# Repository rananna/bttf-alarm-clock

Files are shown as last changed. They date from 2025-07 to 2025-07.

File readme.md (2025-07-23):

# Back to the Future - ESP32 Alarm Clock

<p align="center">
  
  
</p>

<p align="center">
  <!-- Replace with a GIF or image of your clock in action! -->
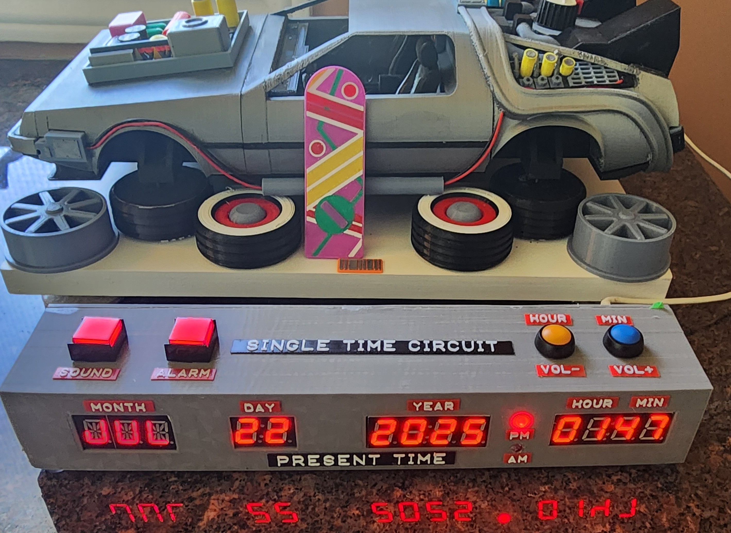
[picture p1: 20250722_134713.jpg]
  
</p>

> **Great Scott!** It appears you've stumbled upon the schematics for a temporal displacement alarm clock. While this device can't actually travel through time (flux capacitor technology is still a bit tricky), it brings the iconic look and feel of the DeLorean's time circuits right to your nightstand. Using the power of an ESP32 and a little bit of 1.21-gigawatt... I mean, 5-volt... ingenuity, this clock connects to your local WiFi network to display the precise date and time. You can set a "Destination Time" alarm and a "Last Time Departed" sleep schedule, all configurable from a web interface. So, fire it up, but be warned: once this baby hits 88 miles per hour on the display, you're going to see some serious stuff!

---

### Table of Contents
- [Quick Start](#quick-start)
- [Features](#features)
- [Bill of Materials (BOM)](#bill-of-materials-bom)
- [Software & Libraries](#software--libraries)
- [Wiring Guide](#wiring-guide)
- [Installation & Setup](#installation--setup)
- [Usage](#usage)
  - [Web Interface](#web-interface)
  - [Physical Buttons](#physical-buttons)
- [Troubleshooting](#troubleshooting)
- [Example Usage](#example-usage)
 - [Video Demo](#video-demo)
- [Contributing](#contributing)
- [License](#license)
- [Acknowledgements](#acknowledgements)

## Quick Start

For experienced makers:
1.  **Gather Components**: Check the [Bill of Materials](#bill-of-materials-bom).
2.  **Assemble Hardware**: Solder components and follow the [Wiring Guide](#wiring-guide).
3.  **Prepare SD Card**: Format a MicroSD card (FAT32), create an `/mp3` folder, and copy sound files named `0001.mp3`, `0002.mp3`, etc., one by one in order.
4.  **Flash Firmware**: Open the project in the Arduino IDE or PlatformIO, install the required libraries, and upload the code to your ESP32.
5.  **Configure WiFi**: After flashing, connect to the `bttf-clock` WiFi network with your phone/PC; a captive portal will appear, allowing you to connect the clock to your home network.
6.  **Configure Clock**: Access the web interface at `http://bttf-alarmclock.local` to set the time zone, alarm, and other features.

    *Note:* If the clock is in Access Point mode (i.e., it couldn't connect to a saved WiFi network), the alphanumeric display will show "AP" to indicate this mode.
## Features

<p align="center">
  <!-- Replace with a GIF or image of your clock in action! -->
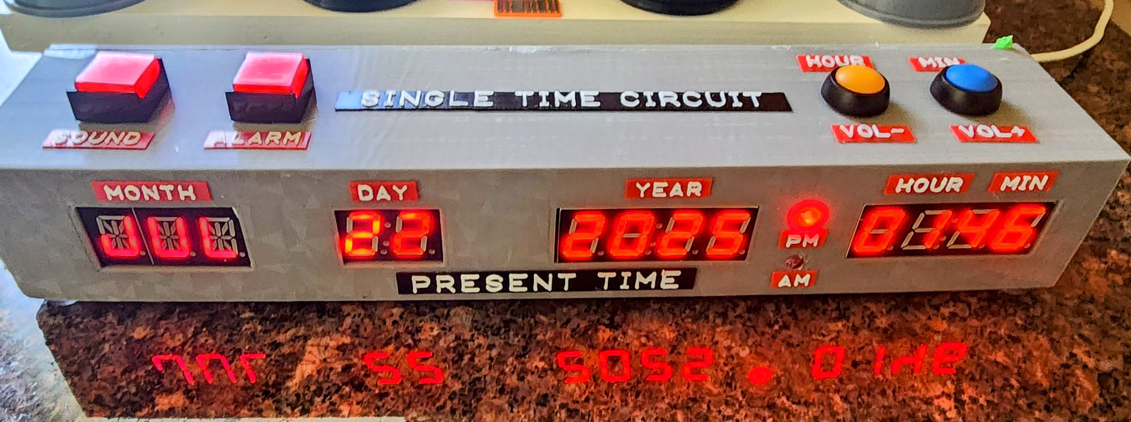
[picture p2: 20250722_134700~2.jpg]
  
</p>

### Video Demo

You can see the BTTF clock booting up [here](https://youtu.be/V0ri4ddPnqE?si=vd6oWths4MbNTJP2)

This project is packed with features to create an authentic and highly functional alarm clock:

*   **BTTF-Themed Display Layout**: Four displays work together to show the current date and time.
    *   **Month**: An alphanumeric display shows the three-letter month abbreviation (e.g., `JUL`).
    *   **Day**: A 7-segment display shows the day of the month.
    *   **Year**: A 7-segment display shows the full year.
    *   **Time**: A 7-segment display shows the current hour and minute, with a blinking colon.
*   **Accurate & Automatic Time**:
    *   **NTP Time Synchronization**: Automatically fetches and syncs time from multiple fallback NTP servers for high reliability.
    *   **Full Time Zone Support**: Includes automatic Daylight Saving Time adjustments, configurable via the web UI.
*   **Complete Web Interface**:
    *   **Web Configuration Portal**: Configure all settings easily from any device on your network via a web browser at `http://bttf-alarmclock.local`.
    *   **WiFi Manager**: Simple initial WiFi setup using a captive portal. No need to hardcode credentials.
*   **Advanced Alarm System**:
    *   **Configurable Alarm**: Set alarm time, toggle on/off, and configure snooze duration from the web UI or physical buttons.
    *   **Snooze Functionality**: Snooze the alarm with a press of a button.
*   **Authentic Experience**:
    *   **Sound Effects**: Plays iconic sounds from the movie for alarms and animations using a DFPlayer Mini MP3 module.
    *   **Time Travel Animations**: Watch the displays go haywire and the speedometer hit 88 MPH at configurable intervals!
*   **Customization & Convenience**:
    *   **Power Saving Mode**: Displays automatically turn off during user-defined "sleep" hours to save power and avoid nighttime glare.
    *   **Over-The-Air (OTA) Updates**: Update the firmware wirelessly over your WiFi network.
    *   **Web UI Themes**: Change the color scheme of the web interface to match your favorite BTTF aesthetic.
    *   **Physical Button Controls**: Full control over core functions without needing the web UI.

## Bill of Materials (BOM)

This project requires a handful of common electronics components. Below is a consolidated Bill of Materials (BOM) for everything you'll need to assemble the clock. The links provided are examples; feel free to source components from your preferred supplier.

| Category | Component | Qty | Notes |
| :--- | :--- | :---: | :--- |
| **Microcontroller** | [ESP32 Dev Module](https://www.aliexpress.com/item/1005006212080137.html) | 1 | The brain of the project. Any ESP32 with enough GPIO pins will work. |
| **Audio** | [DFPlayer Mini MP3 Module](https://www.aliexpress.com/item/1005008228039985.html) | 1 | For playing sound effects. |
| | [MicroSD Card](https://www.aliexpress.com/item/1005008978876553.html) | 1 | 1GB or larger, formatted to FAT16 or FAT32. For storing MP3 files. |
| | [Small Speaker](https://www.aliexpress.com/item/1005006682079525.html) | 1 | A small 8 Ohm speaker (e.g., 0.5W or 1W) for sound output. |
| **Displays** | [TM1637 7-Segment Display](https://www.aliexpress.com/item/1005001582129952.html) | 3 | 4-digit displays for Day, Year, and Time. |
| | [Adafruit AlphaNum4 Display](https://www.aliexpress.com/item/1005001593666162.html) | 1 | 14-segment I2C display for the month. Any HT16K33-based display should work. |
| **User Input** | [Lighted Tactile Push Buttons](https://www.aliexpress.com/item/1005007163972572.html) | 2 | For Set/Stop and Sound/Toggle. |
| | [Tactile Push Buttons](https://www.aliexpress.com/item/1005002622143638.html) | 2 | For Hour and Minute. |
| **Indicators** | [5mm LEDs](https://www.aliexpress.com/item/1005003912454852.html) | 2 | For the AM/PM indicators. Any color. |
| **Passive Components** | [10kΩ Resistors](https://www.aliexpress.com/item/1005008722480918.html) | 4 | Pull-down resistors for the buttons. |
| | [220-330Ω Resistors](https://www.aliexpress.com/item/1005002091320103.html) | 4 | Current-limiting resistors for all LEDs (AM, PM, and button LEDs). |
| | [Wago-style Lever Nuts](https://www.aliexpress.com/item/1005009152825193.html) | (Optional) | For cleaner power distribution. |
| **Prototyping** | Solderless Breadboard (optional) | 1 | For initial assembly and testing. |
| | [Dupont Jumper Wires](https://www.aliexpress.com/item/1005003641187997.html) | 1 set | Male-to-Male and Male-to-Female. |
| | 5V Power Supply | 1 | Minimum 1A recommended, especially for the DFPlayer Mini. |
| | [Wago-style Lever Nuts](https://www.aliexpress.com/item/1005009152825193.html) | (Optional) | For cleaner power distribution. |

## Software & Libraries

This project is built using the Arduino framework for the ESP32. You will need to install the following libraries through the Arduino IDE Library Manager or PlatformIO:

| Library | Author | Purpose | Link |
| --- | --- | --- | --- |
| `WiFiManager` | tzapu | For the WiFi connection portal. | [GitHub](https://github.com/tzapu/WiFiManager) |
| `Adafruit GFX Library` | Adafruit | Core graphics library. | [GitHub](https://github.com/adafruit/Adafruit-GFX-Library) |
| `Adafruit LED Backpack Library` | Adafruit | Drives the AlphaNum4 display. | [GitHub](https://github.com/adafruit/Adafruit_LED_Backpack) |
| `DFRobotDFPlayerMini` | DFRobot | Controls the MP3 player module. | [GitHub](https://github.com/DFRobot/DFRobotDFPlayerMini) |
| `ESPAsyncWebServer` | me-no-dev | Hosts the web configuration interface.| [GitHub](https://github.com/me-no-dev/ESPAsyncWebServer) |
| `AsyncTCP` | me-no-dev | Required by ESPAsyncWebServer. | [GitHub](https://github.com/me-no-dev/AsyncTCP) |
| `arduinoJson` | bblanchon | Handles data for the web API. | [GitHub](https://github.com/bblanchon/ArduinoJson) |
| `TM1637` | Avishay Orpaz | Drives the 7-segment displays. | [GitHub](https://github.com/avishorp/TM1637) |

## Wiring Guide

This section provides a detailed overview of how to connect all components to the ESP32. It's highly recommended to assemble the circuit on a breadboard first to test the connections before soldering.

<p align="center">
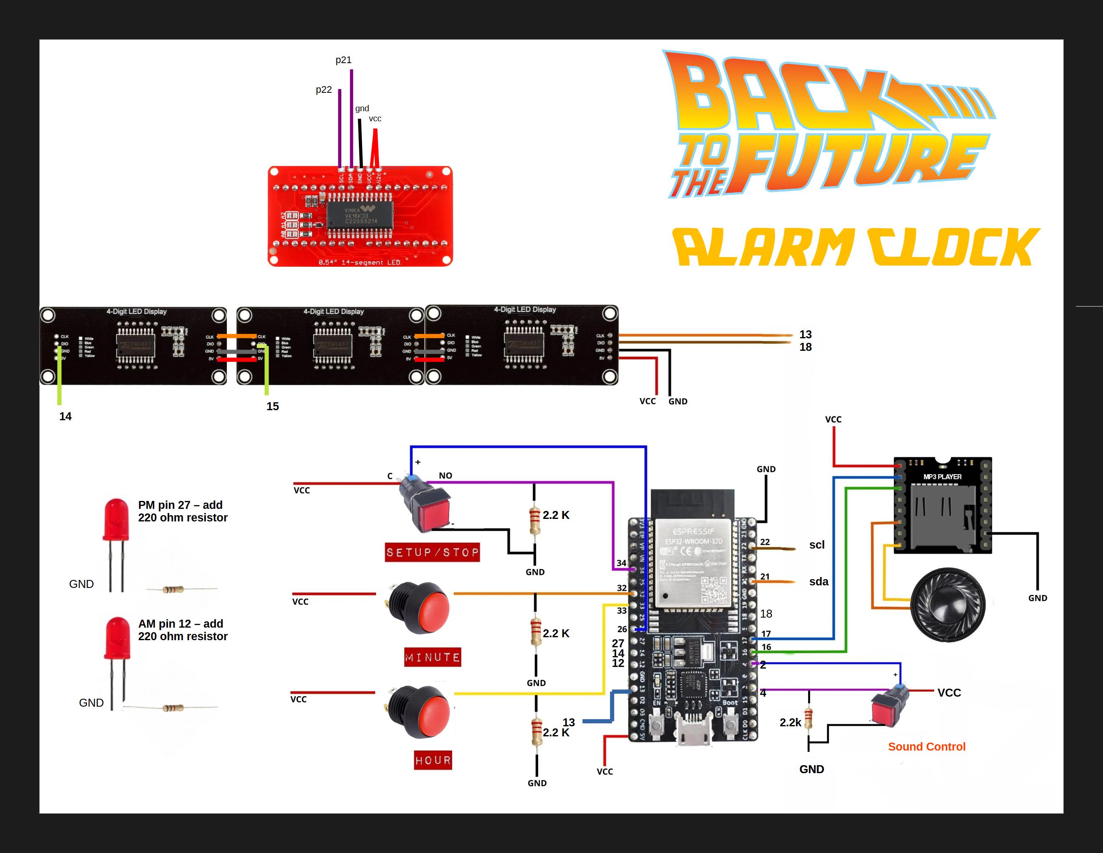
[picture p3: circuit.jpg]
  
</p>

### Power Distribution
**Pro-Tip for Power Rails:** Managing multiple power and ground connections on a breadboard can get messy. For a much cleaner and more reliable setup, consider using **Wago-style lever-nut connectors**. You can run a single wire from your 5V source to one connector and another from GND to a second. Then, simply plug all the individual component VCC and GND wires into their respective connectors. This creates solid, secure power rails without soldering.

All components require a connection to power (VCC) and ground (GND).
*   **5V Power**: Connect the **VIN** pin of the ESP32 to the positive (5V) rail of your power source. Connect the VCC pins of all three TM1637 displays, the Adafruit AlphaNum4 display, and the DFPlayer Mini to this 5V rail.
*   **Ground**: Connect a **GND** pin from the ESP32 to the common ground rail. Connect the GND pins of all displays, the DFPlayer Mini, all buttons, and the negative (cathode) side of all LEDs (via their current-limiting resistors) to this ground rail.
### Display Connections

The clock uses four separate displays that are controlled differently.

### TM1637 7-Segment Displays
These three displays share a common clock (CLK) line to save pins, but each has a unique data (DIO) line.

| Display Function | Pin | ESP32 GPIO |
| --- |:---:| :---: |
| **All TM1637s (Shared)** | CLK | 13 |
| Day of Month | DIO | 18 |
| Year | DIO | 15 |
| Time (HH:MM) | DIO | 14 |

### Adafruit AlphaNum4 Alphanumeric Display
This display uses the I2C communication protocol.

| Component | Pin | ESP32 GPIO |
| --- |:---:| :---: |
| **Adafruit AlphaNum4 (I2C)** | SDA | 21 |
| | SCL | 22 |
### Audio Connections

The DFPlayer Mini module communicates with the ESP32 using a serial (UART) connection.

| Component | Pin | ESP32 GPIO | Notes |
| --- |:---:| :---: | --- |
| **DFPlayer Mini**| RX  |  17 (TXD2) | Connects to the ESP32's **TX** pin. |
| | TX  |  16 (RXD2) | Connects to the ESP32's **RX** pin. |
| | SPK_1 | Speaker +  | Connect one speaker wire here. |
| | SPK_2 | Speaker -  | Connect the other speaker wire here. |

### Button & LED Connections

The buttons require pull-down resistors (e.g., 10kΩ) to prevent floating inputs. The LEDs require current-limiting resistors (e.g., 220-330Ω) to prevent them from burning out.

| Component | ESP32 GPIO | Notes |
| --- | :---: | --- |
| Set/Stop Button | 34 | Connect one side to 3.3V and the other to the GPIO pin. Add a 10kΩ pull-down resistor from the GPIO pin to GND. |
| Set/Sound Button | 4 | Connect one side to 3.3V and the other to the GPIO pin. Add a 10kΩ pull-down resistor from the GPIO pin to GND. |
| Hour Button | 33 | Connect one side to 3.3V and the other to the GPIO pin. Add a 10kΩ pull-down resistor from the GPIO pin to GND. |
| Minute Button | 32 | Connect one side to 3.3V and the other to the GPIO pin. Add a 10kΩ pull-down resistor from the GPIO pin to GND. |
| **AM LED** | 27 | Connect the anode (+) to this pin. Connect cathode (-) to GND via a 220-330Ω resistor. |
| **PM LED** | 12 | Connect the anode (+) to this pin. Connect cathode (-) to GND via a 220-330Ω resistor. |
| Set/Stop LED | 26 | Connect the anode (+) to this pin. Connect cathode (-) to GND via a 220-330Ω resistor. |
| Set/Sound LED | 2 | Connect the anode (+) to this pin. Connect cathode (-) to GND via a 220-330Ω resistor. |
## Installation & Setup

### 1. 3D Print the Housing

A custom-designed housing is available to give your clock an authentic, finished look. The 3D model is provided as a Bambu Studio project file (`bambu studio clock.3mf`).
#
This project's housing is based on the incredible "Back to the Future Single Time Circuit" model by TerryB on MakerWorld. A huge thank you to to him for his original work and the mods he made at my request to the files! You can find the original model [here](https://makerworld.com/en/models/1154106-back-to-the-future-single-time-circuit#profileId-1537667).

*   **File**: `bambu studio clock.3mf`
*   **Recommended Filament**: For a realistic metallic look, use a metallic grey or silver PLA/PETG filament.
*   **Build Plate**: Printing on a patterned or textured PEI build plate can enhance the metallic effect and give the surface a unique finish.
*   **Infill**: Use an infill of **50% or higher** to ensure the housing is sturdy and durable.
*   **Labels**: The labels for the displays and buttons can be printed using the included `bttf-labels.3mf` Bambu Studio project file. To achieve the white text on the black background, you will need to set a filament color change to **white** at the correct layer height within Bambu Studio.

### 2. Hardware Assembly

Solder all the components together as described in the **Wiring Guide**. Double-check all your connections, especially power and ground, before applying power.

**Pro-Tip:** For initial assembly and prototyping, **Dupont plug-in jumper wires** are highly recommended. They eliminate the need for soldering and make wiring much simpler and reversible. For a more permanent and robust final build, consider soldering components to a perfboard.

### 3. Prepare the SD Card

1.  Format a MicroSD card to **FAT16** or **FAT32**.
2.  Create a folder named `mp3` in the root of the SD card.
3.  Copy your sound effect files into the `mp3` folder. The files must be named in a specific four-digit format: `0001.mp3`, `0002.mp3`, etc.
    *   **Important**: Due to how the DFPlayer Mini module indexes files, you must copy the files to the SD card **one by one, in numerical order**. Start with `0001.mp3`, then `0002.mp3`, and so on. Do not copy them all at once, as this can cause the wrong sounds to play.
    *   `0002.mp3`: Time travel / primary alarm sound.
    *   `0008.mp3`: "Power of Love" easter egg sound
    *   `0010.mp3`: Sleep mode activation sound
    *   `0013.mp3`: "On" or positive confirmation sound
    *   `0014.mp3`: "Off" or negative confirmation sound
    *   ... and other random sounds for the alarm (`0001.mp3` - `0009.mp3`)
4.  Insert the SD card into the DFPlayer Mini module.

### 4. Flash the Firmware
1.  **Set Up Your IDE**: This project can be compiled using the **Arduino IDE** or **PlatformIO** (in an editor like VS Code).
    *   **Arduino IDE**: Install the ESP32 board definitions.
    *   **PlatformIO**: The `platformio.ini` file should handle the setup automatically.
2.  **Install Libraries**: Using your IDE's Library Manager, install all the libraries listed in the Software & Libraries section.
3.  **Configure Default Time Zone (Optional)**: The time zone can be set from the web interface later. However, to set the initial default, open the `.ino` file and find the `timezoneString` in the `defaultSettings` struct. Change it to match your local time zone. You can find a list of valid POSIX TZ strings here.
4.  **Upload Code**: Select your ESP32 board model and the correct COM port, then compile and upload the sketch.
### 5. WiFi Configuration

1.  On the first boot (or after resetting WiFi credentials), the clock will create its own WiFi network with the SSID `bttf-clock`.
2.  Connect to this network with your phone or computer.
3.  A captive portal page should automatically open in your browser. If it doesn't, navigate to `192.168.4.1`.
4.  Click "Configure WiFi", select your home WiFi network from the list, and enter your password.
5.  Click "Save". The clock will restart and automatically connect to your network.

## Usage

### Web Interface

Once connected to your WiFi, you can access the full configuration panel by navigating to **http://bttf-alarmclock.local/** in your web browser.

<p align="center">
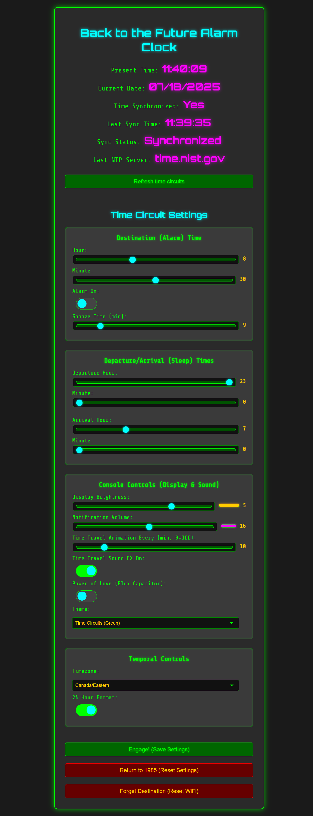
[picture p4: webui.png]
Web UI
  
</p>

From here, you can control all aspects of the clock.
#### Time Circuit Settings
*   **Destination (Alarm) Time**: Use the sliders to set the hour and minute for your alarm.
*   **Alarm On/Off**: A toggle switch to enable or disable the alarm. The `SET/STOP` LED on the clock will light up when the alarm is enabled.
*   **Snooze Time**: A slider to set the snooze duration in minutes (1-59).

#### Departure/Arrival (Sleep) Times
*   These settings define a "sleep" period where the displays will turn off to save power and prevent light disturbance at night.
*   **Departure**: The time the displays will turn off.
*   **Arrival**: The time the displays will turn back on.

#### Display & Sound Settings
*   **Display Brightness**: Adjusts the brightness of all LED displays.
*   **Notification Volume**: Sets the volume for all sound effects from the DFPlayer Mini.
*   **Time Travel Animation Every (min, 0=Off)**: Sets how often (in minutes) the "time travel" animation plays. Set to 0 to disable it.
*   **Time Travel Sound FX On**: A toggle to enable or disable all sound effects, including the alarm. The `SET/SOUND` LED on the clock will light up when sound is enabled.
*   **Power of Love (Flux Capacitor)**: A toggle that triggers the "Power of Love" easter egg sound. This is a one-time trigger and will turn itself off after being activated.
*   **Theme**: A dropdown to change the color scheme of the web interface.

#### Time Settings
*   **Timezone**: Select your local timezone from the dropdown list. This is crucial for correct time display and automatic Daylight Saving Time adjustments.
*   **24 Hour Format**: A toggle to switch the time display between 24-hour format (e.g., 14:30) and 12-hour AM/PM format (e.g., 02:30 PM).

#### Device Management
*   **Save All Settings**: Saves all your changes to the ESP32's memory.
*   **Reset to Default Settings**: Resets all clock settings to their original values and reboots the device.
*   **Reset WiFi Credentials**: Clears the saved WiFi network, reboots the device, and puts it back into AP mode for new WiFi configuration.
### Physical Buttons

The clock can also be operated using the four physical buttons for core functions.

*   **SET/STOP Button**:
    *   **Single Press**: Toggles the main alarm On or Off. A confirmation sound will play, and the corresponding LED will turn on or off.
    *   **Press and Hold**: Enters alarm setting mode.
        *   The time display shows the current alarm time.
        *   While holding, use the **HOUR** and **MINUTE** buttons to adjust the alarm.
        *   Release to save the new alarm time.
    *   **During Alarm**: Stops the currently sounding alarm.

*   **SET/SOUND Button**:
    *   **Single Press**: Toggles all sound effects On or Off. A confirmation sound will play, and the corresponding LED will turn on or off.

*   **HOUR Button**:
    *   **Default Mode**: Decreases the sound effect volume by one step.
    *   **Alarm Setup Mode**: Increments the alarm hour.
    *   **During Alarm**: Activates the **Snooze** function.

*   **MINUTE Button**:
    *   **Default Mode**: Increases the sound effect volume by one step.
    *   **Alarm Setup Mode**: Increments the alarm minute.
    *   **During Alarm**: Activates the **Snooze** function.

*   **Easter Egg**:
    *   Press and hold the **HOUR** and **MINUTE** buttons simultaneously to trigger the "Power of Love" sound effect!

## Troubleshooting
Having trouble? Here are some common issues and their solutions.
*   **Web Interface Not Loading (`bttf-alarmclock.local` doesn't work)**
    *   **mDNS Issues**: Not all networks or operating systems handle `.local` addresses well. Find the clock's IP address from your router's connected devices list or by watching the Serial Monitor in the Arduino IDE when the clock boots up. You can then access the UI by typing the IP address directly into your browser.
    *   **WiFi Connection**: Ensure the ESP32 is connected to your WiFi. If not, it will revert to AP mode (`bttf-clock` network).

*   **Displays Are Not Working or Showing Gibberish**
    *   **TM1637s (Day, Year, Time)**: Double-check the `CLK` and `DIO` wiring. All three displays share the same `CLK` pin, but each must have its own unique `DIO` pin connected to the correct GPIO on the ESP32.
    *   **AlphaNum4 (Month)**: This is an I2C device. Verify that `SDA` and `SCL` are not swapped. You can run an "I2C Scanner" sketch on the ESP32 to confirm the display is detected at address `0x70`.
    *   **Power**: Ensure all displays are receiving a stable 5V.

*   **No Sound from DFPlayer Mini**
    *   **Power Supply**: The DFPlayer can be sensitive to power fluctuations. Ensure you are using a stable 5V power supply capable of providing at least 1A. Powering everything directly from a computer's USB port might be insufficient.
    *   **Wiring**: The most common issue is swapping the RX/TX lines. The DFPlayer's `RX` pin must connect to the ESP32's **TX** pin (`GPIO 17`), and the DFPlayer's `TX` pin must connect to the ESP32's **RX** pin (`GPIO 16`).
    *   **SD Card Format**: The card **must** be formatted as FAT16 or FAT32.
    *   **File Structure**: Ensure there is a folder named `mp3` in the root of the SD card and that your sound files are inside it.
    *   **File Naming & Copying**: Files must be named `0001.mp3`, `0002.mp3`, etc. **Crucially**, you must copy them to the SD card one by one, in numerical order. If you copy them all at once, the player's file index will be incorrect.

*   **Time is Incorrect**
    *   **WiFi**: The clock needs an internet connection to sync with NTP servers.
    *   **Timezone**: Make sure you have selected the correct timezone in the web UI and saved the settings.
    *   **Firewall**: Some restrictive networks may block NTP traffic (UDP port 123).

*   **Buttons Are Unresponsive or Behave Erratically**
    *   **Pull-Down Resistors**: Each button requires a 10kΩ pull-down resistor connecting its GPIO pin to Ground (GND). Without these, the input pin is "floating" and can trigger randomly.
    *   **Wiring**: Double-check that one side of the button is connected to 3.3V and the other side is connected to both the GPIO pin and the pull-down resistor.

## Example Usage

Let's walk through a common scenario: setting up the clock for a typical weekday morning.

**Goal:**
*   Wake up at **7:30 AM**.
*   The displays should turn off at night, from **11:00 PM** to **6:30 AM**.
*   The clock is located in **New York (Eastern Time)**.
*   The display brightness and alarm volume should be at a comfortable, medium level.
*   The "Time Travel" animation should play every **15 minutes**.
*   Both the alarm and general sound effects should be enabled.

Here’s how you would configure this using the web interface at `http://bttf-alarmclock.local/`:

1.  **Set the Alarm Time**
    In the "Destination (Alarm) Time" section, adjust the sliders to your desired wake-up time.
    ```
    Destination Hour: 7
    Destination Minute: 30
    ```

2.  **Enable the Alarm**
    Ensure the main alarm is active by flipping the toggle switch. The `SET/STOP` LED on the clock will light up.
    ```
    Alarm On/Off: On
    ```

3.  **Set the Sleep Period**
    In the "Departure/Arrival (Sleep) Times" section, define when the displays should turn off and on.
    ```
    Departure (Sleep): 23:00
    Arrival (Wake): 6:30
    ```

4.  **Set the Timezone**
    In the "Temporal Controls" section, select the correct timezone from the dropdown menu to ensure accurate time, including DST changes.
    ```
    Timezone: Canada/Eastern
    ```

5.  **Adjust Display Brightness**
    In "Console Controls," set the `Display Brightness` slider to a medium level, like `4`.
    ```
    Display Brightness: 4
    ```

6.  **Adjust Sound Volume**
    Set the `Notification Volume` slider to a moderate level, such as `20`.
    ```
    Notification Volume: 20
    ```

7.  **Configure Animation Frequency**
    Set how often the time travel animation plays. A 15-minute interval is a good starting point.
    ```
    Time Travel Animation Every: 15 min
    ```

8.  **Enable All Sounds**
    Make sure the `Time Travel Sound FX On` toggle is enabled. The `SET/SOUND` LED on the clock will light up.
    ```
    Time Travel Sound FX On: On
    ```

9.  **Save Your Settings**
    Click the **Engage! (Save Settings)** button at the bottom of the page to apply all your changes.

10. **All Set!**
    Your clock is now configured. It will wake you up at 7:30 AM, stay dark overnight, and provide some fun temporal displacement effects throughout the day.

---

## Contributing

Contributions are what make the open-source community such an amazing place to learn, inspire, and create. Any contributions you make are **greatly appreciated**.

If you have a suggestion that would make this better, please fork the repo and create a pull request. You can also simply open an issue with the tag "enhancement". Don't forget to give the project a star! Thanks again!

---

## License

```text
MIT License

Copyright (c) 2025 Randall North

Permission is hereby granted, free of charge, to any person obtaining a copy
of this software and associated documentation files (the "Software"), to deal
in the Software without restriction, including without limitation the rights
to use, copy, modify, merge, publish, distribute, sublicense, and/or sell
copies of the Software, and to permit persons to whom the Software is
furnished to do so, subject to the following conditions:

The above copyright notice and this permission notice shall be included in all
copies or substantial portions of the Software.

THE SOFTWARE IS PROVIDED "AS IS", WITHOUT WARRANTY OF ANY KIND, EXPRESS OR
IMPLIED, INCLUDING BUT NOT LIMITED TO THE WARRANTIES OF MERCHANTABILITY,
FITNESS FOR A PARTICULAR PURPOSE AND NONINFRINGEMENT. IN NO EVENT SHALL THE
AUTHORS OR COPYRIGHT HOLDERS BE LIABLE FOR ANY CLAIM, DAMAGES OR OTHER
LIABILITY, WHETHER IN AN ACTION OF CONTRACT, TORT OR OTHERWISE, ARISING FROM,
OUT OF OR IN CONNECTION WITH THE SOFTWARE OR THE USE OR OTHER DEALINGS IN THE
SOFTWARE.
```

---

## Acknowledgements

This project wouldn't be possible without the hard work of the open-source community and the creators of the fantastic libraries used. Special thanks to the teams behind the ESP32 Arduino core, WiFiManager, and all the Adafruit and DFRobot libraries. A huge thank you to TerryB on MakerWorld for the original 3D model design and for making modifications upon request.

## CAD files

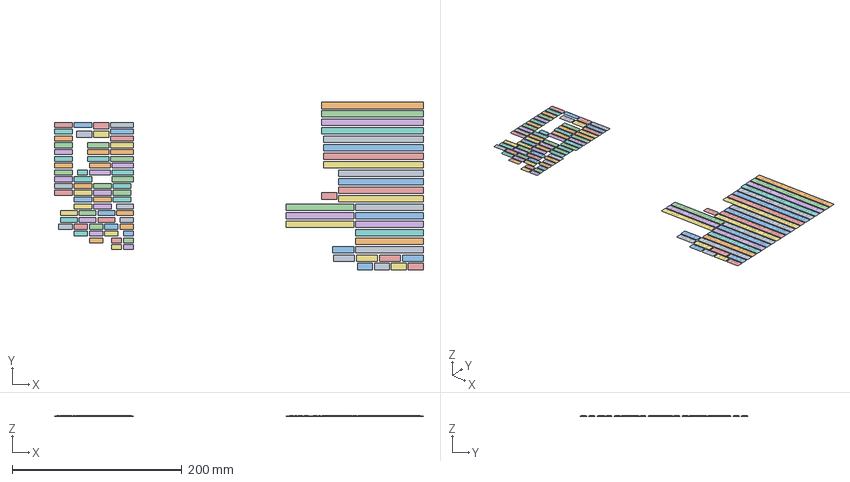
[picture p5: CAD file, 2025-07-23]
bttf-labels.3mf
434.7 x 198.0 x 1.00 mm
month v1.stl x 6
single time circuit.stl x 4
last time departed v1.stl x 4
SOUND.stl x 4
ALARM.stl x 4
destination time v1.stl x 4
TIME CIRCUITS.stl x 5
present time v1.stl x 4
88 v1.stl x 3
year v2.stl x 9
hour v2.stl x 15
set v1.stl x 5
TO v1.stl x 5
VOL-.stl x 4
VOL+.stl x 4
min v2.stl x 7
day v1.stl x 3
am v1.stl x 3
pm v2.stl x 3

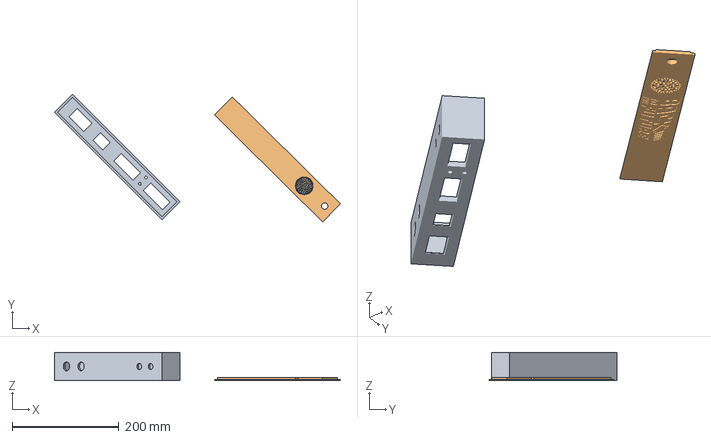
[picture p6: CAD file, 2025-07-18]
clock.3mf
536.0 x 239.6 x 53.0 mm
singlerow.stl
back with speaker.stl

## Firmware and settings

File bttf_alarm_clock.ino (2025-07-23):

/**
 * 
 * Back to the Future Alarm Clock
 * =================================  
 * Author: Randall North              // Your name here
 * Version: 1.0.8 (July 7, 2025)  // Version number and release date
 * Board: ESP32 Dev Module        // Target hardware
 * License: MIT                   // Software license
 * 
 * Description:
 * A WiFi-connected alarm clock inspired by Back to the Future time circuits,
 * with multiple displays showing current, destination and last departure times.
 * 
 * Features:
 * - NTP time synchronization with multiple fallback servers    // Reliable time keeping
 * - Configurable alarm with snooze functionality               // Wake-up capability
 * - OTA updates for easy firmware upgrades                     // Remote updating
 * - Display brightness control with day/night settings         // Eye comfort
 * - Full web configuration interface (http://bttf-alarmclock.local) // Easy configuration
 * - Time travel animations and sound effects                   // Movie authenticity
 * - Multiple display themes (Green, Red, Amber, Blue)          // User customization
 * - Power saving mode during specified hours                   // Energy efficiency
 * - Full time zone support including daylight saving times     // Timekeeping flexibility
 */

#include "Arduino.h"                // Core Arduino functions
#include "TM1637Display.h"          // Library for 7-segment LED displays
#include "WiFiManager.h"            // Handles WiFi connection and captive portal
#include <Wire.h>                   // I2C communication protocol library
#include "Adafruit_GFX.h"           // Graphics library for display control
#include "Adafruit_LEDBackpack.h"   // Controls LED matrix and 7-segment displays
#include "ArduinoOTA.h"             // Over-The-Air firmware updates
#include "ESPmDNS.h"                // Multicast DNS for local hostname resolution
#include "DFRobotDFPlayerMini.h"    // Controls MP3 module for sound effects
#include <WiFi.h>                   // ESP32 WiFi functionality
#include <ESPAsyncWebServer.h>      // Non-blocking web server for configuration interface
#include <Preferences.h>            // ESP32 non-volatile storage for persistent settings
#include <ArduinoJson.h>            // JSON parsing for web API communication
#include <time.h>                   // Time functions for clock operations
#include <WiFiUdp.h>                // UDP protocol for NTP time synchronization
//#include <NTPClient.h>              // NTP client for Internet time synchronization

#define green_CLK 13              // Clock pin for all TM1637 displays
#define green1_DIO 18             // Data pin for the first TM1637 display
#define green2_DIO 15             // Data pin for the second TM1637 display
#define green3_DIO 14             // Data pin for the third TM1637 display
#define greenAM 27                // Output pin to control the AM indicator LED
#define greenPM 12                // Output pin to control the PM indicator LED
#define SET_STOP_BUTTON 34        // Input pin for the Set/Stop button (used to stop alarm or enter settings mode)
#define SET_STOP_LED 26           // Output pin for the LED indicating Set/Stop status
#define SET_SOUND_BUTTON 4        // Input pin for the Set/Sound button (likely for testing sounds or toggling sound-related settings)
#define SET_SOUND_LED 2             // Output pin for the LED indicating Set/Sound status
#define HOUR_BUTTON 33            // Input pin for incrementing the hour in settings mode
#define MINUTE_BUTTON 32          // Input pin for incrementing the minute in settings mode
#define FPSerial Serial1            // Serial port used for communication with the DFPlayer Mini MP3 module

static bool nighttimeonlyonce=true;
struct tm timeinfo;
bool sleeptimeactive = false;
const byte RXD2 = 16;           // RX pin connected to the DFPlayer Mini's TX pin
const byte TXD2 = 17;           // TX pin connected to the DFPlayer Mini's RX pin


DFRobotDFPlayerMini myDFPlayer;
void printDetail(uint8_t type, int value);

float counter = 0;

int sound_minutes = 0;        // Variable to store minutes for sound-related settings (currently unused)
int sound_hours = 0;          // Variable to store hours for sound-related settings (currently unused)

int flag_alarm = 0 ;           // Flag to indicate if the alarm is currently active

int h=0;                      // General purpose variable, often used as a counter in loops or for small calculations
int Play_finished = 0;        // Flag to indicate if the currently playing sound/track has finished
int easter_egg = 0;           // Flag to track if the "easter egg" mode (special animation/sound) is active

int sleeping_time_in_minutes; // Calculated start time of the sleep mode in minutes (from midnight)


int wake_time_in_minutes;     // Calculated end time of the sleep mode in minutes (from midnight)

int currenthour;             // Stores the current hour (0-23)
int currentminute;           // Stores the current minute (0-59)
int current_time_in_minutes;  // Calculated current time in minutes (from midnight)

//int brightness=30;
//int brightness=30;            // Commented-out variable, likely intended for overall brightness control (but 'currentSettings.brightness' is used instead)


uint8_t segments[4];


bool res;
int Hour = 0;
//========================USEFUL VARIABLES=============================
const char* months[] = {"JAN", "FEB", "MAR", "APR", "MAY", "JUN", "JUL", "AUG", "SEP", "OCT","NOV","DEC","VOL","SND","ALM","EGG","SNZ"};
                                        // Array of month abbreviations and other codes for display on the alphanumeric display
                                        // Includes codes for Volume, Sound, Alarm, Easter Egg, and Snooze
int randomTime = 0;               // Unused variable, possibly intended for generating random times for display
float currentSpeed = 0; // Store the last green1ed speed
float targetSpeed = 88;           // Target speed for the initial "time travel" animation (88 mph)
unsigned long previousMillis = 0;   // General-purpose variable to store the last time an event occurred (in milliseconds)
unsigned long previoussecMillis = 0;// Stores the last time the second-based blink event occurred
unsigned long previoustestMillis = 0;// Another time tracking variable, likely for animations or other periodic events
//const long interval = 3600000; // Interval in milliseconds (1 hour)

const long secinterval = 500; // Interval in milliseconds (0.5 sec ) blink on every second
// unsigned long soundinterval =  60000; // Interval in milliseconds 30 sec )
static int lastexecutedhour=-1;
static int lastexecutedminute=-1;
// --- Animation Control Variables ---
// Prevents animations from triggering too frequently and tracks their timing
unsigned long lastAnimationTriggerTime = 0;  // Timestamp of last animation in milliseconds

int UTC = -4;                      // Unused variable, likely intended to store the UTC offset in hours (but TZ_INFO is used instead)
const long utcOffsetInSeconds = 3600; // Unused constant, likely intended for UTC offset in seconds (but TZ_INFO is used instead)
// Note: Module connection pins defined later in the code

bool changesMade = false;           // Flag to track if settings were modified and need saving

// --- Configuration ---
#define MDNS_HOSTNAME "bttf-alarmclock"   // Hostname for mDNS, allowing access via http://bttf-alarmclock.local/





// Time Zone (for Canada/Eastern - EDT). This string sets the TZ environment variable for `time.h` functions.
// Format: "STDoffsetDSToffset,startdate/time,enddate/time"
// Example: "EST5EDT,M3.2.0,M11.1.0" means:
//   EST = Eastern Standard Time, 5 hours behind UTC (UTC-5)
//   EDT = Eastern Daylight Time (during DST), 4 hours behind UTC (UTC-4)
//   M3.2.0 = Month 3 (March), 2nd Sunday, 00:00:00 (start of DST)
//   M11.1.0 = Month 11 (November), 1st Sunday, 00:00:00 (end of DST)
const char* TZ_INFO = "EST5EDT,M3.2.0,M11.1.0"; 

// --- NTP Server configuration for the custom client ---
// List of NTP server hostnames to try in order.
const char* NTP_SERVERS[] = {
    "pool.ntp.org",
    "time.google.com",
    "time.nist.gov",
    "us.pool.ntp.org" // Another common pool
};
const int NUM_NTP_SERVERS = sizeof(NTP_SERVERS) / sizeof(NTP_SERVERS[0]); // Calculate number of servers
int currentNtpServerIndex = 0; // Index of the server currently being used for retries

const int NTP_PACKET_SIZE = 48; // Standard size of an NTP time stamp message (in bytes)
 byte packetBuffer[NTP_PACKET_SIZE]; // Buffer to hold incoming and outgoing NTP packets

// A UDP instance to let us send and receive packets over UDP for NTP
WiFiUDP Udp;
// Create an NTPClient instance, passing the WiFiUDP object and other parameters

// NTP Sync variables to manage sync status, timing, and retry logic.
unsigned long lastNtpRequestSent = 0; // Stores the millis() when the last NTP request was sent
const long NTP_BASE_INTERVAL_MS = 60000;   // Base interval (60 seconds) to request new time if successful
unsigned long currentNtpInterval = NTP_BASE_INTERVAL_MS; // Current interval, adjusted by exponential backoff on failure
const unsigned long NTP_MAX_INTERVAL_MS = 30 * 60 * 1000; // Max interval (30 minutes) for exponential backoff
unsigned int ntpFailedAttempts = 0; // Counter for consecutive failed NTP sync attempts, used for backoff
                                    // --- Global Objects ---
bool timeSynchronized = false;        // Flag to indicate if time has been successfully synchronized at least once
time_t lastNtpSyncTime = 0;           // Stores the Unix timestamp of the last successful NTP sync
String syncStatusMessage = "Initializing..."; // Detailed message about current sync status for web UI
String currentNtpServerUsed = "None"; // To display which NTP server was last used/attempted for web UI

// --- Global Objects ---
WiFiManager wifiManager;      // WiFiManager object for network setup and provisioning
AsyncWebServer server(80);    // AsyncWebServer object, listening on port 80 (standard HTTP for web UI)
Preferences preferences;      // Preferences object for Non-Volatile Storage (NVS)
// Server-sent events to refresh client browsers
AsyncEventSource events("/events");
// Structure to hold alarm clock settings. This struct's contents are saved/loaded from NVS.
struct ClockSettings {
  int destinationHour;
  int destinationMinute;
  bool alarmOnOff;
  int snoozeMinutes;
  int departureHour;    // Start hour for 'sleep' mode brightness
  int departureMinute;
  int arrivalHour;      // End hour for 'sleep' mode brightness
  int arrivalMinute;
  int brightness;       // Overall display brightness (e.g., for LEDs, 0-7)
  int notificationVolume; // Volume level for alarms/notifications (e.g., 0-30)
  bool timeTravelSoundToggle; // Renamed: Enable/disable time travel sound effects/alarm sounds
  bool powerOfLoveToggle; // New: Toggle for "Power of Love" (e.g., Flux Capacitor animation/light)
  int timeTravelAnimationInterval; // New: Interval in minutes for display animation (0 for disabled)
  bool displayFormat24h; // True for 24-hour format (HH:MM), false for 12-hour (HH:MM AM/PM)
  int theme;            // Theme index (e.g., 0 for Green, 1 for Red, 2 for Amber, 3 for Blue)
  char timezoneString[64];  // String to store the selected timezone
};

// Initialize with default settings - these values are used if NVS read fails or for first boot.
ClockSettings defaultSettings = { 
  .destinationHour = 8,
  .destinationMinute = 30,
  .alarmOnOff = false,
  .snoozeMinutes = 10, // default snooze time in minutes
  .departureHour = 23, // 11 PM (Start of sleep mode)
  .departureMinute = 0,
  .arrivalHour = 7,    // 7 AM (End of sleep mode)
  .arrivalMinute = 0,
  .brightness = 7,
  .notificationVolume = 15,
  .timeTravelSoundToggle = true, // Default to true
  .powerOfLoveToggle = false, // Default to false
  .timeTravelAnimationInterval = 10, // Default: Animate every 10 minutes
  .displayFormat24h = false,
  .theme = 0,             // Default to the first theme (Green)
  .timezoneString = "EST5EDT,M3.2.0,M11.1.0"  // Default timezone Canada/Eastern
};

ClockSettings currentSettings; // This variable will hold the actively used settings (loaded from NVS or default)

// --- Function Prototypes ---
// Declaring functions before they are defined allows the compiler to know their signatures.
void configModeCallback(WiFiManager *myWiFiManager); // Callback for WiFiManager config portal entry
void loadSettings();                                 // Load settings from NVS
void saveSettings();                                 // Save settings to NVS
void resetDefaultSettings();                         // Reset settings to factory defaults
void handleApiTime(AsyncWebServerRequest *request);  // Web API handler for current time/sync status
void handleApiSettings(AsyncWebServerRequest *request); // Web API handler for retrieving all settings
void handleApiSaveSettings(AsyncWebServerRequest *request); // Web API handler for saving settings
void handleApiStatus(AsyncWebServerRequest *request); // Web API handler for WiFi/network status
void handleApiResetDefaults(AsyncWebServerRequest *request); // Web API handler for resetting settings
void handleApiResetWifi(AsyncWebServerRequest *request); // Web API handler for resetting WiFi credentials
void notFound(AsyncWebServerRequest *request);       // Web server 404 handler
void triggerBrowserRefresh();






// --- HTML, CSS, JavaScript (Embedded as Raw Strings) ---
// These are served by the web server to provide a configuration interface.
// Using R"raw(...)raw" allows multi-line strings without needing escape characters.
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
void loop()

{

    unsigned long currentMillis = millis();
    unsigned long currentsecMillis = millis();
    unsigned long currenttestMillis = millis();
    unsigned long lastYieldTime = millis();
    static bool colonState = false;
    // Handle watchdog
  if (millis() - lastYieldTime > 50) {
    yield();
    lastYieldTime = millis();
  }
  // - Maintaining WiFi connection.
    // - Detecting disconnects and re-attempting connection.
    // - Running the captive portal if WiFi is lost or reset.
    wifiManager.process(); 

    // --- Custom NTP Sync Retry Logic ---
    // Only attempt NTP synchronization if WiFi is currently connected.
    if (WiFi.status() == WL_CONNECTED) {
        // Condition for attempting NTP sync:
        // - `!timeSynchronized`: If time has never been successfully synchronized yet.
        // - `(millis() - lastNtpRequestSent >= currentNtpInterval)`: If the calculated interval
        //   since the last NTP request was sent has elapsed. This handles both normal polling
        //   and exponential backoff for failed attempts.
        if (!timeSynchronized || (millis() - lastNtpRequestSent >= currentNtpInterval)) {
            Serial.printf("Time to attempt NTP sync. Current interval: %lu ms.\n", currentNtpInterval);
            processNTPresponse(); // Call the custom NTP function to send a request and process the response
        }
    } else {
        // If WiFi is disconnected, log this periodically to the serial monitor.
        // This helps in diagnosing network issues and prevents continuous logging.
        if (millis() - lastNtpRequestSent >= 5000) { // Log every 5 seconds if disconnected
            Serial.println("WiFi is disconnected. Cannot attempt NTP sync.");
            lastNtpRequestSent = millis(); // Reset this to prevent spamming serial too fast
        }
    }
    
    //    Periodically retrieve the current time from the ESP32's system clock.
    //    `getLocalTime()` converts the UTC time (set by NTP) to local time
    //    based on the `TZ_INFO` configured earlier.
       if (timeSynchronized)  getLocalTime(&timeinfo);
    //       `// Time is available and current
    //    Use the time components (hour, minute, second) to update the  display.
     //    timeinfo.tm_hour, timeinfo.tm_min, timeinfo.tm_sec, currentSettings.displayFormat24h);
     //date components:
    //    timeinfo.tm_mday, timeinfo.tm_mon + 1, timeinfo.tm_year + 1900);




    
    h=1;
    Play_finished = 0;


    ArduinoOTA.handle();

       //CHECK IF sleep time
  
 
   // set time variables
  

    if (timeSynchronized) {
        // Create a time_t value for the current time
        time_t current_time = mktime(&timeinfo);

        // Create time_t values for departure and arrival times on the current day
        struct tm departure_tm = timeinfo;
        departure_tm.tm_hour = currentSettings.departureHour;
        departure_tm.tm_min = currentSettings.departureMinute;
        departure_tm.tm_sec = 0;
        time_t departure_time = mktime(&departure_tm);

        struct tm arrival_tm = timeinfo;
        arrival_tm.tm_hour = currentSettings.arrivalHour;
        arrival_tm.tm_min = currentSettings.arrivalMinute;
        arrival_tm.tm_sec = 0;
        time_t arrival_time = mktime(&arrival_tm);

        // Adjust for crossing midnight
        if (departure_time > arrival_time) {
            // If departure time is later than arrival time, it means the sleep period crosses midnight.
            // We check if the current time is either after the departure time OR before the arrival time.
            sleeptimeactive = (current_time >= departure_time || current_time < arrival_time);
        } else {
            // If departure time is earlier than arrival time, the sleep period is within the same day.
            // We check if the current time is between the departure and arrival times.
            sleeptimeactive = (current_time >= departure_time && current_time < arrival_time);
        }

       // Serial.print("Current time: ");
       // Serial.println(current_time);
       // Serial.print("Departure time: ");
       // Serial.println(departure_time);
       // Serial.print("Arrival time: ");
       // Serial.println(arrival_time);
       // Serial.print("Sleep time active: ");
        Serial.println(sleeptimeactive);

    }
    
    //CHECK IF sleep time
  
  if ( sleeptimeactive) {  //greater than sleep start or less than sleep stop am
    //  do nothing during sleep time
  }
  else {
//process the loop normally
  // Check if settings were updated via web interface
  if (changesMade) {
    // Apply new settings
           Serial.println("Web page settings were updated! Performing actions...");
              
               setenv("TZ", currentSettings.timezoneString, 1);
            tzset();
   //change the player volume
    myDFPlayer.volume(currentSettings.notificationVolume);  
    //CHECK TO SEE IF alarmOnOff HAS CHANGED, IF SO CHANGE THE LED STATUS
  if(currentSettings.alarmOnOff == 1){
    digitalWrite(SET_STOP_LED,HIGH);
     }
  else {
       digitalWrite(SET_STOP_LED,LOW);
  }

  //CHECK TO SEE IF timeTravelSoundToggle HAS CHANGED, IF SO CHANGE THE LED STATUS
  if (currentSettings.timeTravelSoundToggle) {
    digitalWrite(SET_SOUND_LED, HIGH);
     }
  else {
       digitalWrite(SET_SOUND_LED,LOW);
  }
    //set the display brightness 
     green1.setBrightness(currentSettings.brightness,1);
     green2.setBrightness(currentSettings.brightness,1);
     green3.setBrightness(currentSettings.brightness,1);
     ht16k33_display.setBrightness(currentSettings.brightness*2);

                 // If time travel sound effects are enabled, trigger them:
            if (currentSettings.timeTravelSoundToggle) {
                Serial.println("Playing Time Travel Sound FX!");
                // Example: `playTimeTravelSound(currentSettings.notificationVolume);`
                // You'd need an MP3 module or a buzzer to play sounds.
            }

            // If "Power of Love" (Flux Capacitor) is toggled on:
            if (currentSettings.powerOfLoveToggle) {
                Serial.println("Activating Power of Love (Flux Capacitor)!");
                // Example: `activateFluxCapacitorLEDs();`
                // This would control specific LEDs or other visual elements.
               
                if (!sleeptimeactive) myDFPlayer.play(8);
                 currentSettings.powerOfLoveToggle=false;
                saveSettings();
                triggerBrowserRefresh();
                

            }  
 
    changesMade = false;  // Reset flag after processing
  }

    // --- Time Travel Animation Trigger (NEW) ---
    // Only trigger if time is synchronized and animation interval is set (not 0)
    if (timeSynchronized && currentSettings.timeTravelAnimationInterval > 0) {
        unsigned long currentMillis = millis();
        // Convert the animation interval from minutes to milliseconds
        unsigned long intervalMs = (unsigned long)currentSettings.timeTravelAnimationInterval * 60 * 1000; 

        if (currentMillis - lastAnimationTriggerTime >= intervalMs) {
            Serial.printf("Triggering Time Travel Animation (every %d min)!\n", currentSettings.timeTravelAnimationInterval);
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
